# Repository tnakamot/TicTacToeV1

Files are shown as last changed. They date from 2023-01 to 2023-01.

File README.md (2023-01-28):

# Tic-Tac-Toe V1

This is a project to make a Tic-Tac-Toe game using Arduino Nano.

## PCB

 * The PCB has been designed with [KiCAD 6.0.10](https://www.kicad.org/).
 * The KiCAD project is available in [KiCAD/](KiCAD/) directory.

<p float="left">
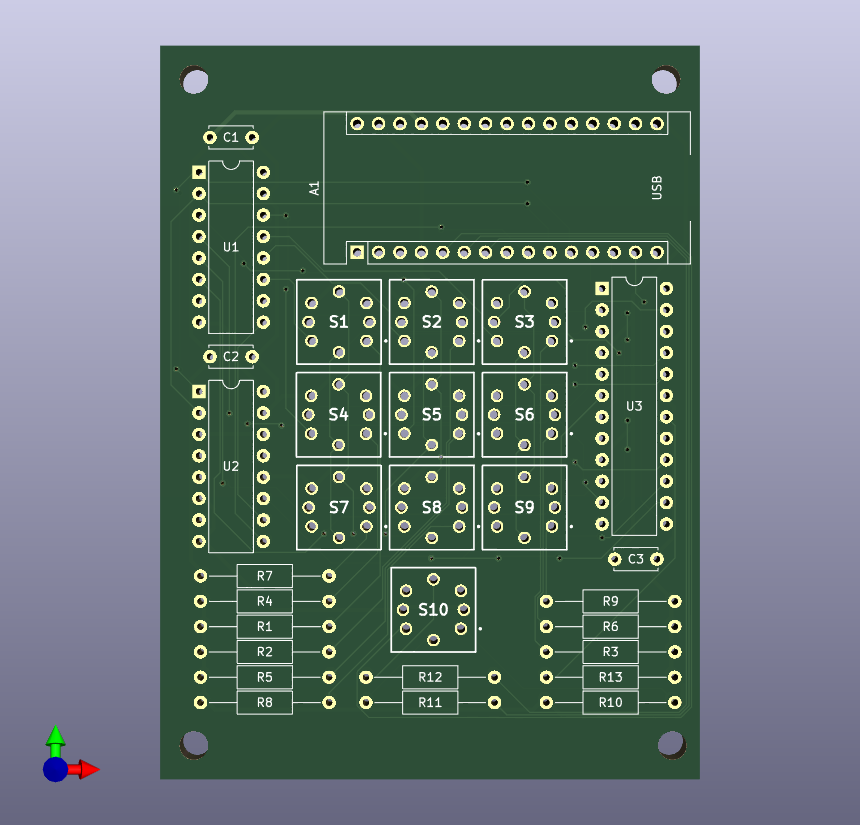
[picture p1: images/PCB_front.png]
    
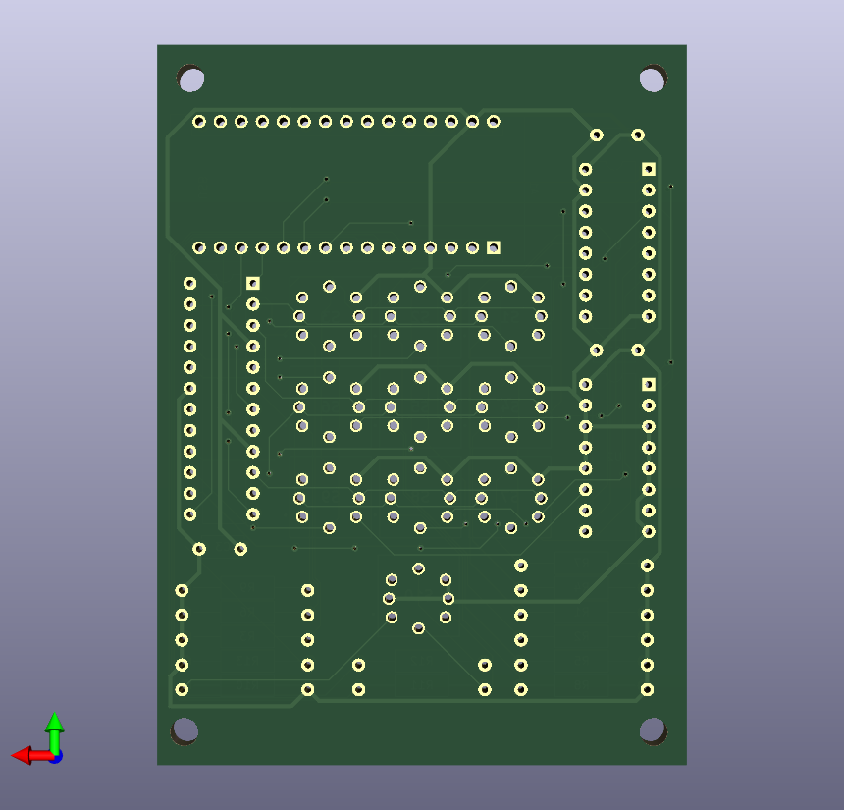
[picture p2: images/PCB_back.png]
    
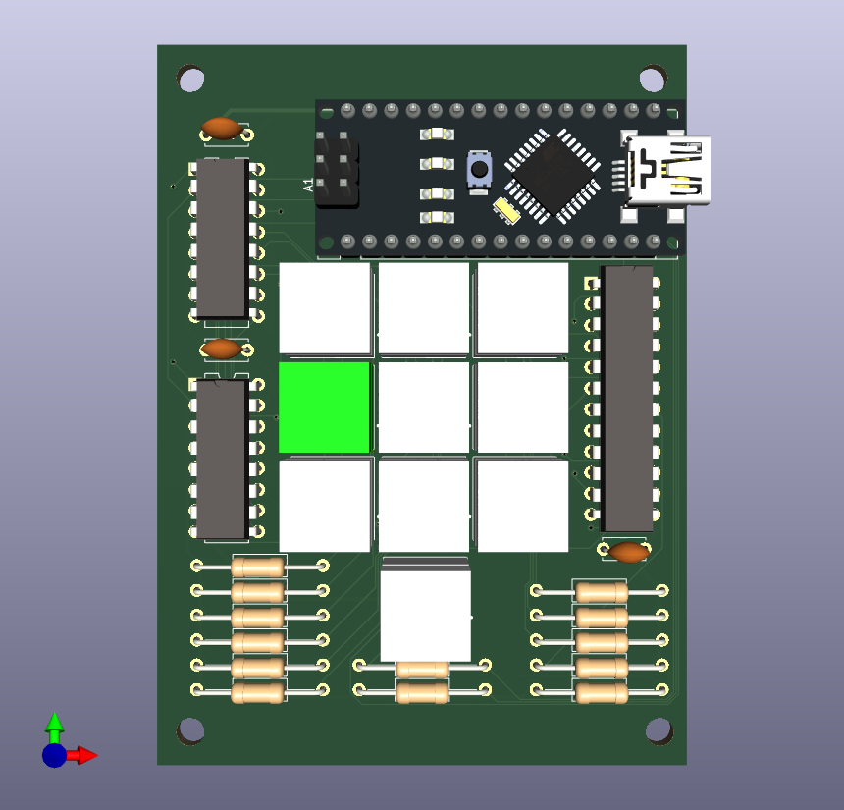
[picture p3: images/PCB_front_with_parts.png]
    
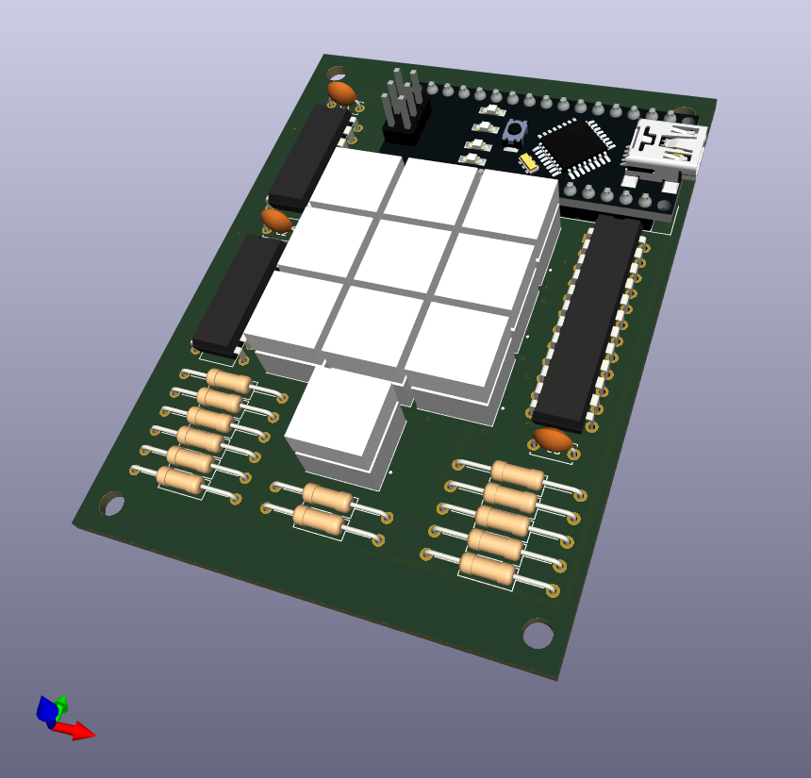
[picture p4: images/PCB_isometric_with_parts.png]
    
</p>

The pictures below show the PCB manufactured by [OSHPARK](https://oshpark.com/).

<p float="left">
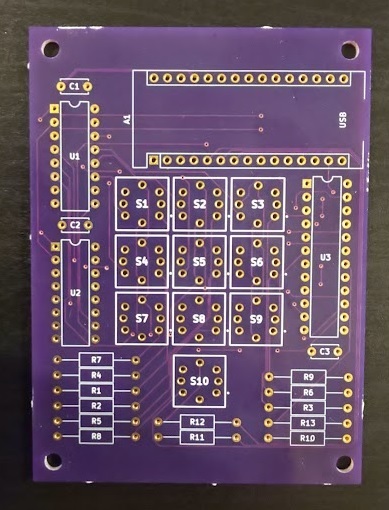
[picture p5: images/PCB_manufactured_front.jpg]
    
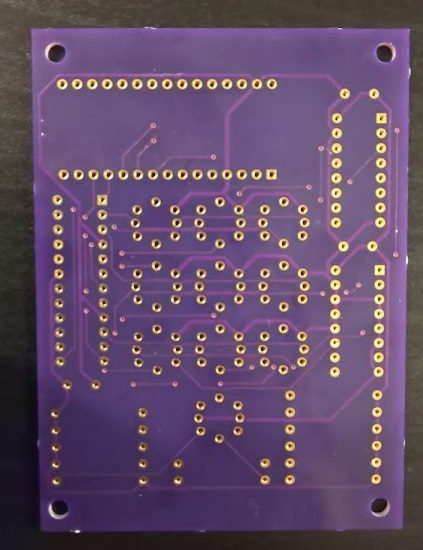
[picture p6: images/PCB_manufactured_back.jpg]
    
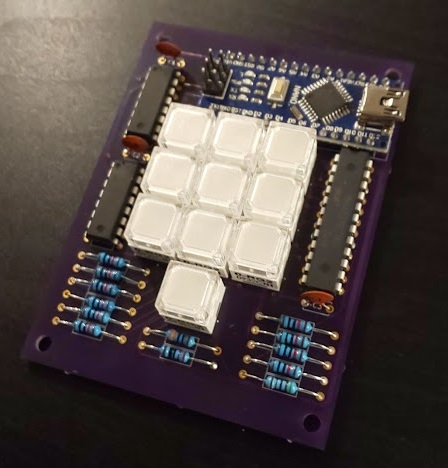
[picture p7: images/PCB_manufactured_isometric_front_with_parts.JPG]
    
</p>
 
## Software

(TODO: explain how to install the software on the Arduino Nano.)

## Parts

The list below shows the parts that this project uses.

 * Arduino Nano
   * [Product webpage at Arduino.cc](https://docs.arduino.cc/hardware/nano)
   * [Datasheet](https://docs.arduino.cc/static/2d169cbfd360faf817882e36b9f69956/A000005-datasheet.pdf)
   * This project uses a compatible clone (Arduino Nano CH340).
 * Omron B3W-9000-RG2C: button with two LEDs (red and green)
   * [Product webpage at Omron](https://components.omron.com/eu-en/products/switches/B3W-9)
   * [Datasheet](https://components.omron.com/eu-en/datasheet_pdf/A167-E1.pdf)
   * [Product page at Mouser](https://www.mouser.com/ProductDetail/Omron-Electronics/B3W-9000-RG2C?qs=QTkYtwcxD6NNQk1oSF8osQ%3D%3D): includes the link to footprint.
   * [3D Model at SnapEDA](https://www.snapeda.com/parts/B3W-9000-RG2C/Omron%20Electronics/view-part/?ref=digikey)
 * Texas Instruments 74HC165: 8-bit parallel-load shift register
   * [Product webpage at Texas Instruments](https://www.ti.com/product/SN74HC165)
   * [Datasheet](https://www.ti.com/lit/ds/symlink/sn74hc165.pdf)
 * Analog Devices MAX7219: serially interfaced, LED display driver
   * [Product webpage at Analog Devices](https://www.analog.com/en/products/max7219.html)
   * [Datasheet](https://www.analog.com/media/en/technical-documentation/data-sheets/MAX7219-MAX7221.pdf)
   * [LedControl - An Arduino library for the MAX7219 and MAX7221](http://wayoda.github.io/LedControl/index.html)
     * This program uses this library to control MAX7219.
     * The page above also explains how to wire up LEDs to MAX7219.
     
## License

TBD

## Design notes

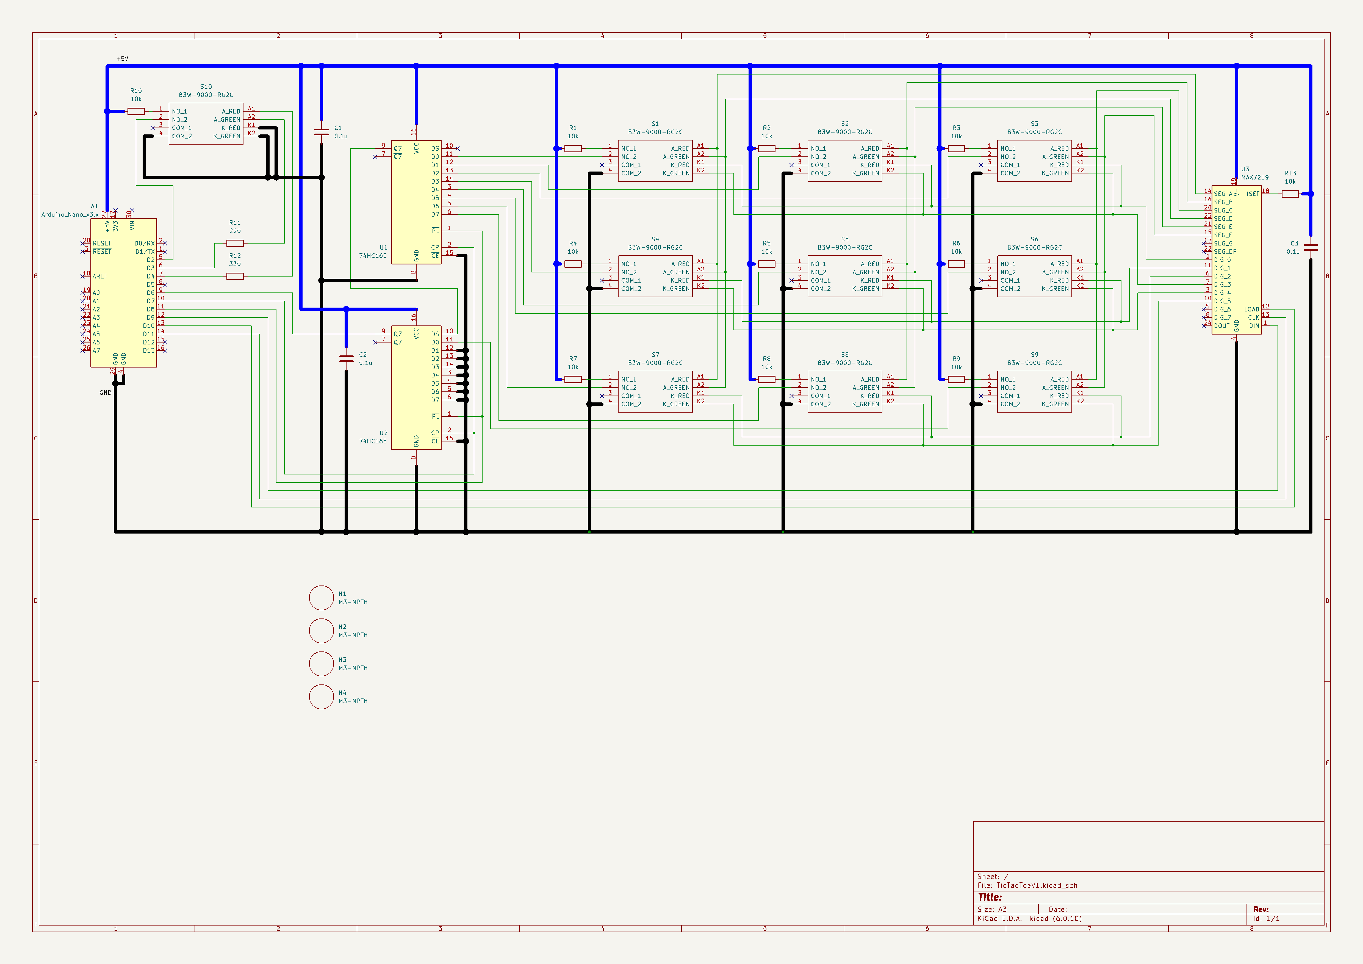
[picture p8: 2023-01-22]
images/schematics.png

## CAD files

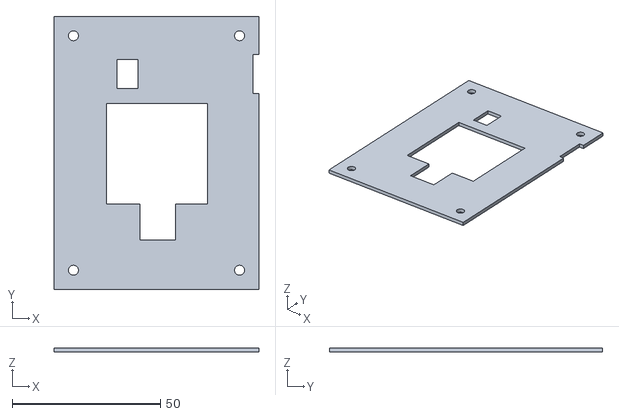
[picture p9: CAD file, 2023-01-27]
FreeCAD/CaseTop.stl
69.0 x 92.0 x 1.50

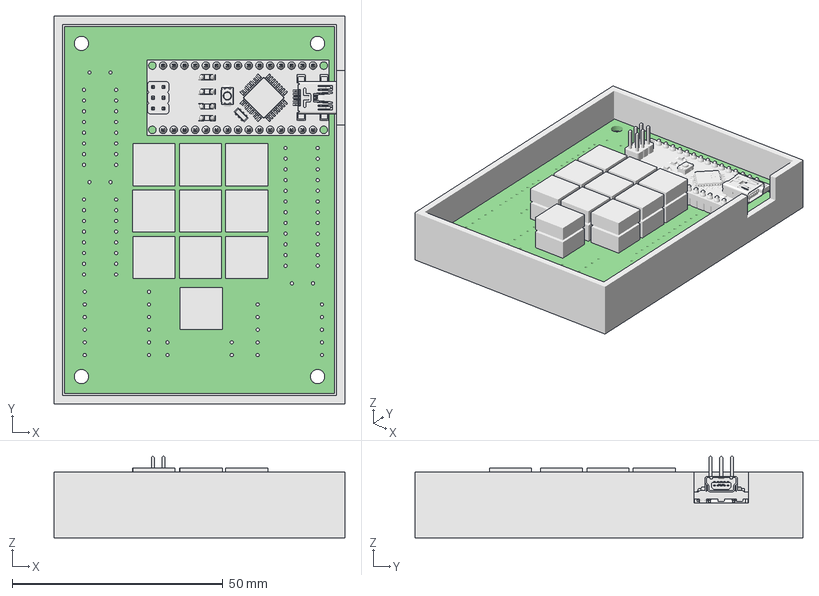
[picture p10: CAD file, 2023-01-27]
FreeCAD/TicTacToeV1_enclosure.FCStd
69.0 x 92.0 x 19.3 mm
TicTacToeV1 PCB
CaseBottom (Meshed)

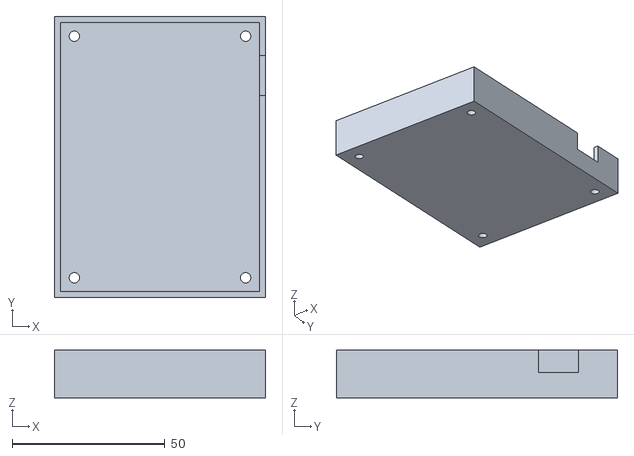
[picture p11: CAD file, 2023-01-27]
FreeCAD/CaseBottom.stl
69.0 x 92.0 x 15.6

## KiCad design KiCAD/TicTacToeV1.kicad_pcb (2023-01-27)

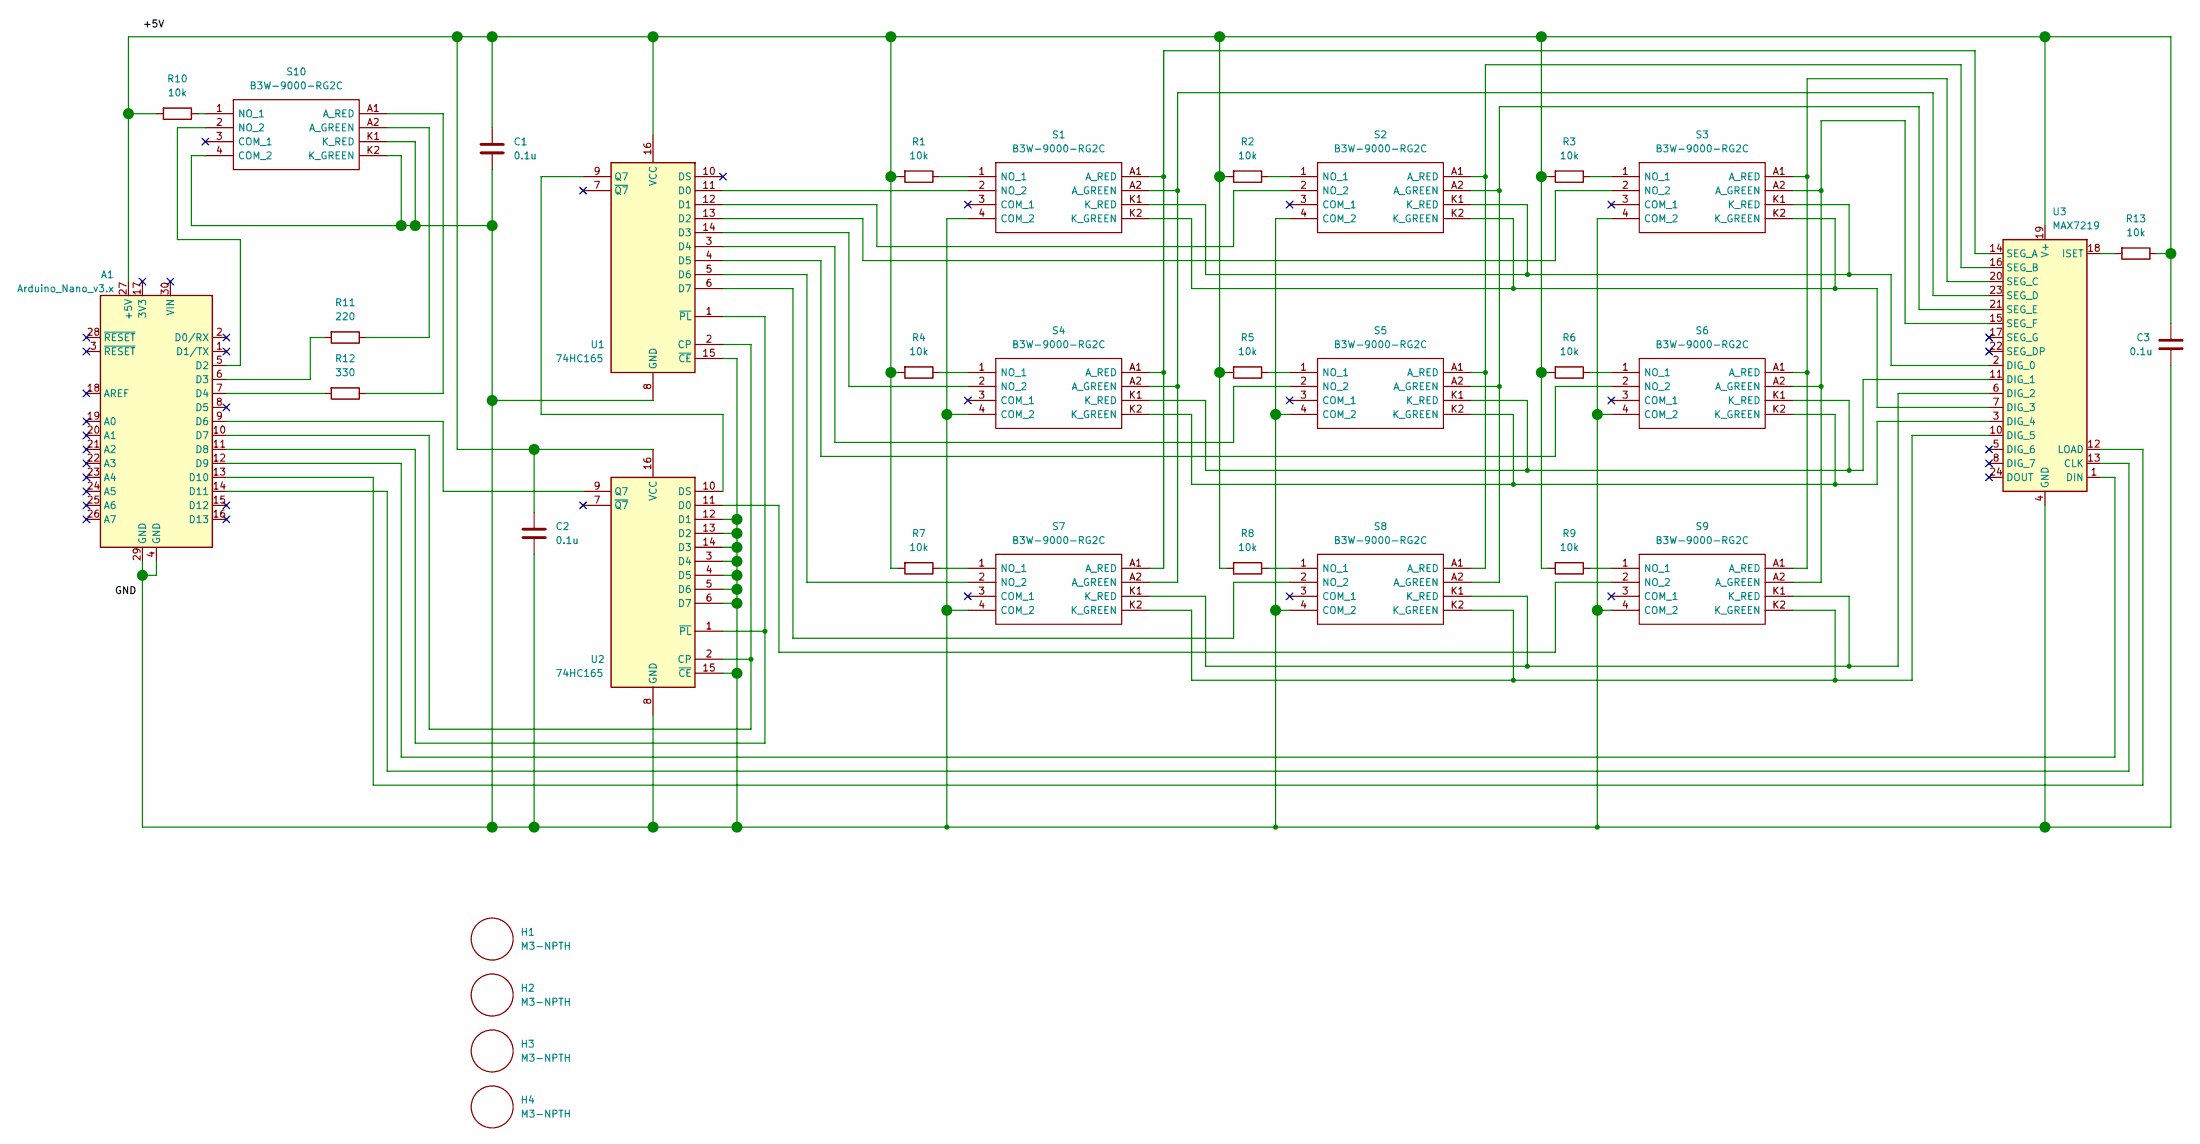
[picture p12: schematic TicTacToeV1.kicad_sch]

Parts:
A1: Arduino_Nano_v3.x; Arduino_Nano
C1, C2, C3: 0.1u; C_Disc_D5.0mm_W2.5mm_P5.00mm
H1, H2, H3, H4: M3-NPTH
R1, R2, R3, R4, R5, R6, R7, R8, R9, R10, R13: 10k; R_Axial_DIN0207_L6.3mm_D2.5mm_P15.24mm_Horizontal
R11: 220; R_Axial_DIN0207_L6.3mm_D2.5mm_P15.24mm_Horizontal
R12: 330; R_Axial_DIN0207_L6.3mm_D2.5mm_P15.24mm_Horizontal
S1, S2, S3, S4, S5, S6, S7, S8, S9, S10: B3W-9000-RG2C; Mouser Part Number 653-B3W-9000-RG2C
U1, U2: 74HC165; DIP-16_W7.62mm
U3: MAX7219; DIP-24_W7.62mm

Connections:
unnamed: A1.5 (D2), S10.2 (NO_2)
unnamed: A1.6 (D3), R11.2
unnamed: A1.7 (D4), R12.2
unnamed: A1.9 (D6), U2.9 (Q7)
unnamed: A1.10 (D7), U1.2 (CP), U2.2 (CP)
unnamed: A1.11 (D8), U1.1 (~PL), U2.1 (~PL)
unnamed: A1.12 (D9), U3.1 (DIN)
unnamed: A1.13 (D10), U3.12 (LOAD)
unnamed: A1.14 (D11), U3.13 (CLK)
unnamed: A1.27 (+5V), C1.1, C2.1, C3.1, R1.2, R2.2, R3.2, R4.2, R5.2, R6.2, R7.2, R8.2, R9.2, R10.2, R13.1, U1.16 (VCC), U2.16 (VCC), U3.19 (V+)
unnamed: A1.4 (GND), A1.29 (GND), C1.2, C2.2, C3.2, S1.4 (COM_2), S2.4 (COM_2), S3.4 (COM_2), S4.4 (COM_2), S5.4 (COM_2), S6.4 (COM_2), S7.4 (COM_2), S8.4 (COM_2), S9.4 (COM_2), S10.4 (COM_2), S10.K1 (K_RED), S10.K2 (K_GREEN), U1.8 (GND), U1.15 (~CE), U2.3 (D4), U2.4 (D5), U2.5 (D6), U2.6 (D7), U2.8 (GND), U2.12 (D1), U2.13 (D2), U2.14 (D3), U2.15 (~CE), U3.4 (GND), U3.9 (GND)
unnamed: R1.1, S1.1 (NO_1)
unnamed: R2.1, S2.1 (NO_1)
unnamed: R3.1, S3.1 (NO_1)
unnamed: R4.1, S4.1 (NO_1)
unnamed: R5.1, S5.1 (NO_1)
unnamed: R6.1, S6.1 (NO_1)
unnamed: R7.1, S7.1 (NO_1)
unnamed: R8.1, S8.1 (NO_1)
unnamed: R9.1, S9.1 (NO_1)
unnamed: R10.1, S10.1 (NO_1)
unnamed: R11.1, S10.A2 (A_GREEN)
unnamed: R12.1, S10.A1 (A_RED)
unnamed: R13.2, U3.18 (ISET)
unnamed: S1.2 (NO_2), U1.11 (D0)
unnamed: S1.A1 (A_RED), S4.A1 (A_RED), S7.A1 (A_RED), U3.14 (SEG_A)
unnamed: S1.A2 (A_GREEN), S4.A2 (A_GREEN), S7.A2 (A_GREEN), U3.23 (SEG_D)
unnamed: S1.K1 (K_RED), S2.K1 (K_RED), S3.K1 (K_RED), U3.2 (DIG_0)
unnamed: S1.K2 (K_GREEN), S2.K2 (K_GREEN), S3.K2 (K_GREEN), U3.7 (DIG_3)
unnamed: S2.2 (NO_2), U1.12 (D1)
unnamed: S2.A1 (A_RED), S5.A1 (A_RED), S8.A1 (A_RED), U3.16 (SEG_B)
unnamed: S2.A2 (A_GREEN), S5.A2 (A_GREEN), S8.A2 (A_GREEN), U3.21 (SEG_E)
unnamed: S3.2 (NO_2), U1.13 (D2)
unnamed: S3.A1 (A_RED), S6.A1 (A_RED), S9.A1 (A_RED), U3.20 (SEG_C)
unnamed: S3.A2 (A_GREEN), S6.A2 (A_GREEN), S9.A2 (A_GREEN), U3.15 (SEG_F)
unnamed: S4.2 (NO_2), U1.14 (D3)
unnamed: S4.K1 (K_RED), S5.K1 (K_RED), S6.K1 (K_RED), U3.11 (DIG_1)
unnamed: S4.K2 (K_GREEN), S5.K2 (K_GREEN), S6.K2 (K_GREEN), U3.3 (DIG_4)
unnamed: S5.2 (NO_2), U1.3 (D4)
unnamed: S6.2 (NO_2), U1.4 (D5)
unnamed: S7.2 (NO_2), U1.5 (D6)
unnamed: S7.K1 (K_RED), S8.K1 (K_RED), S9.K1 (K_RED), U3.6 (DIG_2)
unnamed: S7.K2 (K_GREEN), S8.K2 (K_GREEN), S9.K2 (K_GREEN), U3.10 (DIG_5)
unnamed: S8.2 (NO_2), U1.6 (D7)
unnamed: S9.2 (NO_2), U2.11 (D0)
unnamed: U1.9 (Q7), U2.10 (DS)

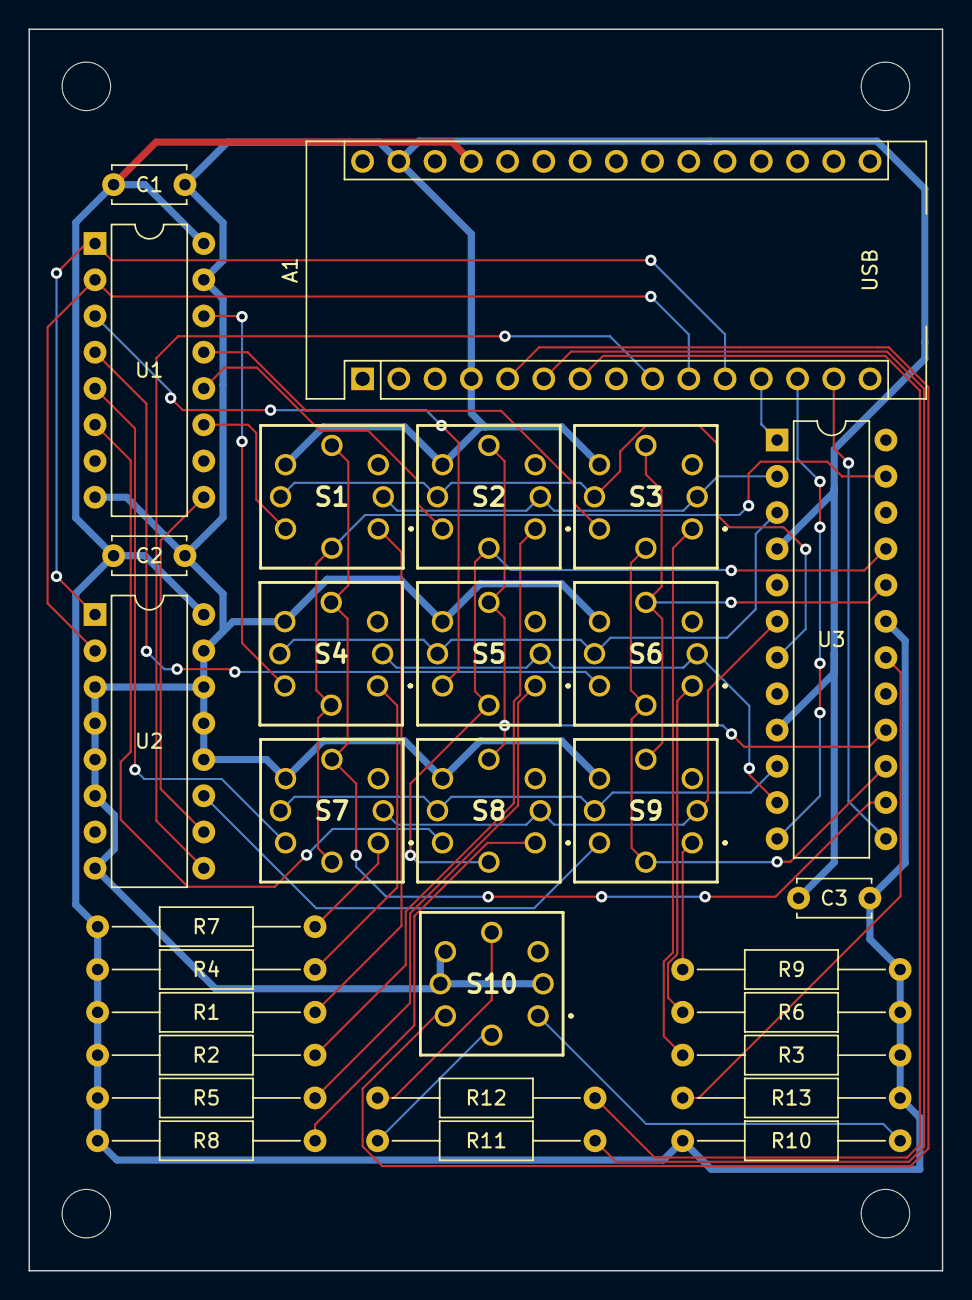
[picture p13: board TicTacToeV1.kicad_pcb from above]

Board: 2 copper layers, 64.0 x 87.0 mm, 34 parts (0 on the bottom side), 46 nets.

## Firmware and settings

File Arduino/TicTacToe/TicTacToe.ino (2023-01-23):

/*
 *    TicTacToe.ino - Arudino Nano program to run Tic-Tac-Toe game.
 *    Copyright (c) 2023 Takashi Nakamoto
 * 
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
 *    This permission notice shall be included in all copies or 
 *    substantial portions of the Software.
 * 
 *    THE SOFTWARE IS PROVIDED "AS IS", WITHOUT WARRANTY OF ANY KIND,
 *    EXPRESS OR IMPLIED, INCLUDING BUT NOT LIMITED TO THE WARRANTIES
 *    OF MERCHANTABILITY, FITNESS FOR A PARTICULAR PURPOSE AND
 *    NONINFRINGEMENT. IN NO EVENT SHALL THE AUTHORS OR COPYRIGHT
 *    HOLDERS BE LIABLE FOR ANY CLAIM, DAMAGES OR OTHER LIABILITY,
 *    WHETHER IN AN ACTION OF CONTRACT, TORT OR OTHERWISE, ARISING
 *    FROM, OUT OF OR IN CONNECTION WITH THE SOFTWARE OR THE USE OR
 *    OTHER DEALINGS IN THE SOFTWARE.
 */

#include "LedControl.h"

/* ===================================================================
 * Digital I/O pin assignment of the Arduino Nano.
 * =================================================================== */
const int RESET_BUTTON             = 2;
const int RESET_BUTTON_GREEN_LED   = 3;
const int RESET_BUTTON_RED_LED     = 4;

const int MAIN_BUTTONS_INPUT_LOAD  = 8;
const int MAIN_BUTTONS_INPUT_CLOCK = 7;
const int MAIN_BUTTONS_INPUT_DATA  = 6;

const int MAX7219_CLK              = 11;
const int MAX7219_LOAD             = 10;
const int MAX7219_DIN              = 9;

/* ===================================================================
 * Program settings.
 * =================================================================== */

// Serial port baud rate for debugging.
const int32_t SERIAL_BAUD_RATE = 57600;

/* ===================================================================
 * Global variables.
 * =================================================================== */

// A variable to hold the main state of this program.
enum MainState { START, PLAYING, RED_WIN, GREEN_WIN, DRAW } main_state = START;

// A variable to hold the territory state.
enum TerritoryState {RED, GREEN, NONE} territory_state[3][3];

// An object that represents the LED controller (MAX7219).
LedControl leds = LedControl(MAX7219_DIN, MAX7219_CLK, MAX7219_LOAD, 1);

/* ===================================================================
 * readMainButtonsRawState()
 *
 * This function read the state of the main nine buttons (S1 - S9)
 * from the daisy-chained two 74HC165 shift registers.
 *
 * bitRead(state, i) represents the press/release state of the S(i+1)
 * button where "state" is the value returned by this function. If it
 * is 1, it means that the button is currently pressed.
 *
 * Example:
 *   uint16_t state = readMainButtonsRawState();
 *   Serial.println( bitRead(state, 0) ? "Button S1 is pressed." : "Button S1 is released." );
 * =================================================================== */
uint16_t readMainButtonsRawState()
{
  uint16_t state = 0;

  // Output a pulse to the load pin (PL) of the 74HC165 shift registers
  // so that they read the input states.
  digitalWrite(MAIN_BUTTONS_INPUT_LOAD, LOW);
  delayMicroseconds(5);
  digitalWrite(MAIN_BUTTONS_INPUT_LOAD, HIGH);
  delayMicroseconds(5);

  // Read the first bit from the 74HC165 shift registers.
  state = digitalRead(MAIN_BUTTONS_INPUT_DATA);
  delayMicroseconds(5);

  // Read the rest of the bits from the 74HC165 shift reigsters.
  for (int i = 1; i < 16; i++) {
    digitalWrite(MAIN_BUTTONS_INPUT_CLOCK, HIGH);
    delayMicroseconds(5);
    digitalWrite(MAIN_BUTTONS_INPUT_CLOCK, LOW);
    delayMicroseconds(5);
    state = (state << 1) | (digitalRead(MAIN_BUTTONS_INPUT_DATA) ? 0 : 1);
  }

  return state;
}

/* ===================================================================
 * readButtonsRawState()
 *
 * This function reads the press/release state of all buttons
 * (S1 - S10).
 *
 * bitRead(state, i) represents the press/release state of the S(i+1)
 * button where "state" is the value returned by this function. If it
 * is 1, it means that the button is currently pressed.
 *
 * Example:
 *   uint16_t state = readButtonsRawState();
 *   Serial.println( bitRead(state, 0) ? "Button S1 is pressed." : "Button S1 is released." );
 *   Serial.println( bitRead(state, 1) ? "Button S2 is pressed." : "Button S2 is released." );
 *   Serial.println( bitRead(state, 9) ? "Button S10 is pressed." : "Button S10 is released." );
 * =================================================================== */
uint16_t readButtonsRawState() {
  uint16_t state = readMainButtonsRawState();
  bitWrite(state, 9, digitalRead(RESET_BUTTON) == HIGH ? 0 : 1);
  return state;
}

/* ===================================================================
 * readMainButtonsState()
 *
 * This function reads the press/release state of all buttons
 * (S1 - S10). Only the buttons that have been pressed more than
 * five milliseconds are considered pressed. This function effectively
 * removes the bouncing effect.
 *
 * bitRead(state, i) represents the press/release state of the S(i+1)
 * button where "state" is the value returned by this function. If it
 * is 1, it means that the button is currently pressed.
 *
 * Example:
 *   uint16_t state = readButtonsState();
 *   Serial.println( bitRead(state, 0) ? "Button S1 is pressed." : "Button S1 is released." );
 *   Serial.println( bitRead(state, 1) ? "Button S2 is pressed." : "Button S2 is released." );
 *   Serial.println( bitRead(state, 9) ? "Button S10 is pressed." : "Button S10 is released." );
 * =================================================================== */
uint16_t readButtonsState() {
  uint16_t state1 = readButtonsRawState();
  delay(10);
  uint16_t state2 = readButtonsRawState();
  return state1 & state2;
}

/* ===================================================================
 * readResetButtonState()
 *
 * This function reads the press/release state of the reset button
 * (S10). This function effectively removes the bouncing effect.
 * =================================================================== */
int readResetButtonState() {
  int state1 = digitalRead(RESET_BUTTON);
  delay(10);
  int state2 = digitalRead(RESET_BUTTON);

  if (state1 == LOW && state2 == LOW) {
    return 1;
  } else {
    return 0;
  }
}

/* ===================================================================
 * drawTerritory()
 *
 * Turn on/off red and green LEDs of S1 - S9 based on the 
 * territory_state global variable.
 * =================================================================== */
void drawTerritory() {
  for (int row = 0; row < 3; row++) {
    byte red_row = 0;
    byte green_row = 0;
    
    for (int col = 0; col < 3; col++) {
      if (territory_state[row][col] == RED) {
        red_row = red_row | (B01000000 >> col);
      } else if (territory_state[row][col] == GREEN) {
        green_row = green_row | (B00001000 >> col);
      }
    }

    leds.setRow(0, row, red_row);
    leds.setRow(0, row + 3, green_row);
  }
}

/* ===================================================================
 * evaluateTerritory()
 *
 * Evaluate the territory and returns if the red play wins (RED_WIN),
 * the green play wins (GREEN_WIN), draw because all territories are
 * populated (DRAW) or the game can continue (PLAYING).
 * =================================================================== */
MainState evaluateTerritory() {
  // Judge if the red or green player wins
  for (int i = 0; i < 3; i++) {
    if (territory_state[0][i] == RED &&
        territory_state[1][i] == RED &&
        territory_state[2][i] == RED) {
      return RED_WIN;
    } else if (territory_state[i][0] == RED &&
               territory_state[i][1] == RED &&
               territory_state[i][2] == RED) {
      return RED_WIN;
    } else if (territory_state[0][i] == GREEN &&
               territory_state[1][i] == GREEN &&
               territory_state[2][i] == GREEN) {
      return GREEN_WIN;
    } else if (territory_state[i][0] == GREEN &&
               territory_state[i][1] == GREEN &&
               territory_state[i][2] == GREEN) {
      return GREEN_WIN;
    }
  }

  if (territory_state[0][0] == RED &&
      territory_state[1][1] == RED &&
      territory_state[2][2] == RED) {
    return RED_WIN;
  } else if (territory_state[0][2] == RED &&
             territory_state[1][1] == RED &&
             territory_state[2][0] == RED) {
    return RED_WIN;
  } else if (territory_state[0][0] == GREEN &&
             territory_state[1][1] == GREEN &&
             territory_state[2][2] == GREEN) {
    return GREEN_WIN;
  } else if (territory_state[0][2] == GREEN &&
             territory_state[1][1] == GREEN &&
             territory_state[2][0] == GREEN) {
    return GREEN_WIN;
  }

  // Judge if the play can continue.
  for (int row = 0; row < 3; row++) {
    for (int col = 0; col < 3; col++) {
      if (territory_state[row][col] == NONE) {
        return PLAYING;
      }
    }
  }

  return DRAW;
}

/* ===================================================================
 * setup()
 *
 * Initialization function that is called only once before start
 * calling the loop() function.
 * =================================================================== */
void setup() {
  Serial.begin(SERIAL_BAUD_RATE);
  Serial.println("TicTacToeV1");

  // Digital I/O pin setup for the reset button and its LEDs.
  pinMode(RESET_BUTTON,           INPUT);
  pinMode(RESET_BUTTON_GREEN_LED, OUTPUT);
  pinMode(RESET_BUTTON_RED_LED,   OUTPUT);

  // Digital I/O pin configuraiton for the shift registers 74HC165
  // that read the states of the main nine buttons.
  pinMode(MAIN_BUTTONS_INPUT_LOAD,  OUTPUT);
  pinMode(MAIN_BUTTONS_INPUT_CLOCK, OUTPUT);
  pinMode(MAIN_BUTTONS_INPUT_DATA,  INPUT);

  // Set up MAX7219.
  leds.shutdown(0, false);
  leds.setIntensity(0, 12);
  leds.clearDisplay(0);
}

/* ===================================================================
 * play()
 *
 * Sub loop in which the program continuously waits for the user
 * inputs, and move forward the game play based on the input.
 *
 * This function returns the next state the main programs should 
 * transition to.
 * =================================================================== */
MainState play() {
  enum PlayTurn {RED_TURN, GREEN_TURN} turn = RED_TURN;
  uint16_t buttons_state = 0;

  /*
   * Initialize the territory.
   */
  for (int row = 0; row < 3; row++) {
    for (int col = 0; col < 3; col++) {
      territory_state[row][col] = NONE;
    }
  }
  drawTerritory();
  
  while (true) {
    // Detect the button state change (pressed or released).
    uint16_t buttons_state_new = readButtonsState();
    uint16_t buttons_state_changed = buttons_state ^ buttons_state_new;
    buttons_state = buttons_state_new;

    if (bitRead(buttons_state_changed, 9) && !bitRead(buttons_state_new, 9)) {
      // The reset button (S10 button) was pressed and released.
      // Reset the game.
      return START;
    }

    for (int i = 0; i < 9; i++) {
      if (bitRead(buttons_state_changed, i) && !bitRead(buttons_state_new, i)) {
        // Handle the release event of the S1 - S9 buttons.
        int row = i / 3;
        int col = i % 3;

        // If the button has not been activated yet, turn the
        // color of that territory.
        if (territory_state[row][col] == NONE) {
          if (turn == RED_TURN) {
            territory_state[row][col] = RED;
            turn = GREEN_TURN;
          } else {
            territory_state[row][col] = GREEN;
            turn = RED_TURN;
          }
        }

        MainState result = evaluateTerritory();
        if (result != PLAYING) {
          return result;
        }
      }
    }
    
    drawTerritory();
  }
}

/* ===================================================================
 * draw()
 *
 * Sub loop in which the program continuously waits until the reset
 * button is pressed and released. Flash the reset button during that
 * time.
 * =================================================================== */
void draw() {
  drawTerritory();

  int reset_button_state = 0;
  int count = 0;

  while (true) {
    int reset_button_state_new = readResetButtonState();
    int reset_button_state_changed = reset_button_state ^ reset_button_state_new;
    reset_button_state = reset_button_state_new;

    if (reset_button_state_changed && !reset_button_state_new) {
      // The reset button was released. Finish this function.
      return;
    }

    // Flash the reset button.
    count = count + 1;
    if (count == 1) {
      digitalWrite(RESET_BUTTON_RED_LED, HIGH);
    } else if (count == 10) {
      digitalWrite(RESET_BUTTON_RED_LED, LOW);
      digitalWrite(RESET_BUTTON_GREEN_LED, HIGH);
    } else if (count == 20) {
      digitalWrite(RESET_BUTTON_GREEN_LED, LOW);
    } else if (count == 100) {
      count = 0;
    }
  }
}

/* ===================================================================
 * win()
 *
 * Sub loop in which the program continuously waits until the reset
 * button is pressed and released. Flash the reset button during
 * that time.
 * =================================================================== */
void win(int red) {
  drawTerritory();

  int reset_button_state = 0;
  int count = 0;

  int coord_to_flash[3][2];
  TerritoryState win_state = red ? RED : GREEN;

  for (int i = 0; i < 3; i++) {
    if (territory_state[0][i] == win_state &&
        territory_state[1][i] == win_state &&
        territory_state[2][i] == win_state) {
      coord_to_flash[0][0] = 0;
      coord_to_flash[0][1] = i;
      coord_to_flash[1][0] = 1;
      coord_to_flash[1][1] = i;
      coord_to_flash[2][0] = 2;
      coord_to_flash[2][1] = i;
    } else if (territory_state[i][0] == win_state &&
               territory_state[i][1] == win_state &&
               territory_state[i][2] == win_state) {
      coord_to_flash[0][0] = i;
      coord_to_flash[0][1] = 0;
      coord_to_flash[1][0] = i;
      coord_to_flash[1][1] = 1;
      coord_to_flash[2][0] = i;
      coord_to_flash[2][1] = 2;
    }
  }

  if (territory_state[0][0] == win_state &&
      territory_state[1][1] == win_state &&
      territory_state[2][2] == win_state) {
      coord_to_flash[0][0] = 0;
      coord_to_flash[0][1] = 0;
      coord_to_flash[1][0] = 1;
      coord_to_flash[1][1] = 1;
      coord_to_flash[2][0] = 2;
      coord_to_flash[2][1] = 2;
  } else if (territory_state[0][2] == win_state &&
             territory_state[1][1] == win_state &&
             territory_state[2][0] == win_state) {
      coord_to_flash[0][0] = 0;
      coord_to_flash[0][1] = 2;
      coord_to_flash[1][0] = 1;
      coord_to_flash[1][1] = 1;
      coord_to_flash[2][0] = 2;
      coord_to_flash[2][1] = 0;
  }

  while (true) {
    int reset_button_state_new = readResetButtonState();
    int reset_button_state_changed = reset_button_state ^ reset_button_state_new;
    reset_button_state = reset_button_state_new;

    if (reset_button_state_changed && !reset_button_state_new) {
      // The reset button was released. Finish this function.
      return;
    }

    // Flash the reset button.
    count = count + 1;
    if (count == 1) {
      if (red) {
        digitalWrite(RESET_BUTTON_RED_LED, HIGH);
      } else {
        digitalWrite(RESET_BUTTON_GREEN_LED, HIGH);
      }
    } else if (count == 15) {
      digitalWrite(RESET_BUTTON_RED_LED, LOW);
      digitalWrite(RESET_BUTTON_GREEN_LED, LOW);
    } else if (count == 30) {
      count = 0;
    }

    // Flash the territory.
    if (count == 1) {
      for (int i = 0; i < 3; i++) {
        int row = coord_to_flash[i][0];
        int col = coord_to_flash[i][1];

        territory_state[row][col] = win_state;
      }
      drawTerritory();
    } else if (count == 15) {
      for (int i = 0; i < 3; i++) {
        int row = coord_to_flash[i][0];
        int col = coord_to_flash[i][1];

        territory_state[row][col] = NONE;
      }
      drawTerritory();
    }

    if (count == 30) {
      count = 0;
    }
  }
}

/* ===================================================================
 * loop()
 *
 * Main loop function which is called repeatedly one after another
 * indefinitely.
 * =================================================================== */
void loop() {
  if (main_state == START) {
    // Turn off all LEDs.
    leds.clearDisplay(0);
    digitalWrite(RESET_BUTTON_GREEN_LED, LOW);
    digitalWrite(RESET_BUTTON_RED_LED,   LOW);

    // Start the game.
    main_state = PLAYING;
  } else if (main_state == PLAYING) {
    main_state = play();
  } else if (main_state == RED_WIN) {
    win(1);
    main_state = START;
  } else if (main_state == GREEN_WIN) {
    win(0);
    main_state = START;
  } else if (main_state == DRAW) {
    draw();
    main_state = START;
  } else {
    // This is an unknown state.
    // Flush the LEDs and wait until the user presses the reset button.

    // TODO: implement
  }
}

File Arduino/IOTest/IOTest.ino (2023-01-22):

/*
 *    IOTest.ino - An Arduino Nano program to test input and output for Tic-Tac-Toe V1.
 *    Copyright (c) 2023 Takashi Nakamoto
 * 
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
 *    This permission notice shall be included in all copies or 
 *    substantial portions of the Software.
 * 
 *    THE SOFTWARE IS PROVIDED "AS IS", WITHOUT WARRANTY OF ANY KIND,
 *    EXPRESS OR IMPLIED, INCLUDING BUT NOT LIMITED TO THE WARRANTIES
 *    OF MERCHANTABILITY, FITNESS FOR A PARTICULAR PURPOSE AND
 *    NONINFRINGEMENT. IN NO EVENT SHALL THE AUTHORS OR COPYRIGHT
 *    HOLDERS BE LIABLE FOR ANY CLAIM, DAMAGES OR OTHER LIABILITY,
 *    WHETHER IN AN ACTION OF CONTRACT, TORT OR OTHERWISE, ARISING
 *    FROM, OUT OF OR IN CONNECTION WITH THE SOFTWARE OR THE USE OR
 *    OTHER DEALINGS IN THE SOFTWARE.
 */

#include "LedControl.h"

const int RESET_BUTTON           = 2;
const int RESET_BUTTON_GREEN_LED = 3;
const int RESET_BUTTON_RED_LED   = 4;

const int MAIN_BUTTONS_INPUT_LOAD      = 8;
const int MAIN_BUTTONS_INPUT_CLOCK     = 7;
const int MAIN_BUTTONS_INPUT_DATA      = 6;

const int MAX7219_CLK  = 11;
const int MAX7219_LOAD = 10;
const int MAX7219_DIN  = 9;

int loop_count = 0;
int reset_button_state = 0;

uint16_t main_buttons_state = 0;

LedControl leds = LedControl(MAX7219_DIN, MAX7219_CLK, MAX7219_LOAD, 1);

// Read the state of the main nine buttons from the daisy-chained
//two 74HC165 shift registers.
uint16_t readMainButtonsState()
{
  uint16_t data = 0;

  // Output a pulse to the load pin (PL) of the 74HC165 shift registers
  // so that they read the input states.
  digitalWrite(MAIN_BUTTONS_INPUT_LOAD, LOW);
  delayMicroseconds(5);
  digitalWrite(MAIN_BUTTONS_INPUT_LOAD, HIGH);
  delayMicroseconds(5);

  // Read the first bit from the 74HC165 shift registers.
  data = digitalRead(MAIN_BUTTONS_INPUT_DATA);
  delayMicroseconds(5);

  // Read the rest of the bits from the 74HC165 shift reigsters.
  for (int i = 1; i < 16; i++) {
    digitalWrite(MAIN_BUTTONS_INPUT_CLOCK, HIGH);
    delayMicroseconds(5);
    digitalWrite(MAIN_BUTTONS_INPUT_CLOCK, LOW);
    delayMicroseconds(5);
    data = (data << 1) | (digitalRead(MAIN_BUTTONS_INPUT_DATA));
  }

  return data;
}

void setup() {
  Serial.begin(57600);
  Serial.println("setup");

  // Digital I/O setup for the reset button and its LEDs.
  pinMode(RESET_BUTTON,           INPUT);
  pinMode(RESET_BUTTON_GREEN_LED, OUTPUT);
  pinMode(RESET_BUTTON_RED_LED,   OUTPUT);

  // Pin configuraiton for the shift register 74HC165 that
  // reads the states of the main nine buttons.
  pinMode(MAIN_BUTTONS_INPUT_LOAD,  OUTPUT);
  pinMode(MAIN_BUTTONS_INPUT_CLOCK, OUTPUT);
  pinMode(MAIN_BUTTONS_INPUT_DATA,  INPUT);

  // Set up MAX7219.
  leds.shutdown(0, false);
  leds.setIntensity(0, 12);
  leds.clearDisplay(0);
}

void loop() {
  loop_count = loop_count + 1;
  Serial.print("loop: ");
  Serial.println(loop_count, DEC);

  // Read the status of the reset button.
  reset_button_state = digitalRead(RESET_BUTTON);
  if (reset_button_state == HIGH) {
    Serial.println("Reset button: high");
  } else {
    Serial.println("Reset button: low");
  }

  // Flash LEDs in the reset button.
  if (loop_count % 2 == 0) {
    digitalWrite(RESET_BUTTON_GREEN_LED, HIGH);
    digitalWrite(RESET_BUTTON_RED_LED,   LOW);
  } else {
    digitalWrite(RESET_BUTTON_GREEN_LED, LOW);
    digitalWrite(RESET_BUTTON_RED_LED,   HIGH);
  }

  // Read the state of the main nine buttons.
  main_buttons_state = readMainButtonsState();
  for (int i = 0; i < 9; i++) {
    Serial.print("S");
    Serial.print(i + 1);
    Serial.print(" : ");
    Serial.println(bitRead(main_buttons_state, i) ? "high" : "low");
    
  }

  // Flash LEDs.
  leds.clearDisplay(0);
  if (loop_count % 9 == 0) {
    // Turn on RED on S1 and GREEN on S9.
    leds.setRow(0, 0, B01000000);
    leds.setRow(0, 5, B00000010);
  } else if (loop_count % 9 == 1) {
    // Turn on RED on S2 and GREEN on S1.
    leds.setRow(0, 0, B00100000);
    leds.setRow(0, 3, B00001000);
  } else if (loop_count % 9 == 2) {
    // Turn on RED on S3 and GREEN on S2.
    leds.setRow(0, 0, B00010000);
    leds.setRow(0, 3, B00000100);
  } else if (loop_count % 9 == 3) {
    // Turn on RED on S4 and GREEN on S3.
    leds.setRow(0, 1, B01000000);
    leds.setRow(0, 3, B00000010);
  } else if (loop_count % 9 == 4) {
    // Turn on RED on S5 and GREEN on S4.
    leds.setRow(0, 1, B00100000);
    leds.setRow(0, 4, B00001000);
  } else if (loop_count % 9 == 5) {
    // Turn on RED on S6 and GREEN on S5.
    leds.setRow(0, 1, B00010000);
    leds.setRow(0, 4, B00000100);
  } else if (loop_count % 9 == 6) {
    // Turn on RED on S7 and GREEN on S6.
    leds.setRow(0, 2, B01000000);
    leds.setRow(0, 4, B00000010);
  } else if (loop_count % 9 == 7) {
    // Turn on RED on S8 and GREEN on S7.
    leds.setRow(0, 2, B00100000);
    leds.setRow(0, 5, B00001000);
  } else if (loop_count % 9 == 8) {
    // Turn on RED on S9 and GREEN on S8.
    leds.setRow(0, 2, B00010000);
    leds.setRow(0, 5, B00000100);
  }

  Serial.println("-----");

  delay(1000);
}

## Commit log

2023-01-09 Updated for production by OSHPARK
    [TicTacToeV1.kicad_pcb, TicTacToeV1.kicad_sch]
2023-01-17 Moved the KiCAD project to a sub-directory.
    [TicTacToeV1.kicad_pcb, TicTacToeV1.kicad_sch]
2023-01-22 Updated the register value based on the prototyping on the breadboard.
    [TicTacToeV1.kicad_sch]
2023-01-22 An arduino test code to check the behavior of the reset button and main 9 buttons.
2023-01-22 Makefile for WSL2 environment.
    [TicTacToeV1.kicad_pcb, TicTacToeV1.kicad_sch]
2023-01-22 Print the main button states.
2023-01-22 Imported LedControl class from http://wayoda.github.io/LedControl/index.html
2023-01-22 Code to test the LedControl class.
2023-01-22 Added PCB images from KiCAD.
2023-01-22 Added pitcures of a manufactured PCB.
2023-01-22 Download arduino-cli.exe when it is missing.
2023-01-23 Detect the button state change.
2023-01-23 Detect the button release events only.
2023-01-23 Turn on LEDs when the button is pressed.
2023-01-23 Added the picture of the PCB with parts mounted.
2023-01-23 Fixed the file name typo.
    [TicTacToe.ino]
2023-01-23 Enable the reset button during the play.
2023-01-23 Flash the reset button when the red or green player wins.
2023-01-27 Added case design.
    [CaseBottom.stl, CaseTop.stl, TicTacToeV1.kicad_pcb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]
